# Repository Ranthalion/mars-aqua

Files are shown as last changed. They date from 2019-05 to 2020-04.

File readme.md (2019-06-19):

View this project on [CADLAB.io](https://cadlab.io/project/1833). 

# Mars Aqua Adapter
Adds support for pwm based dimming for Mars Aqua LED lights

Schematic

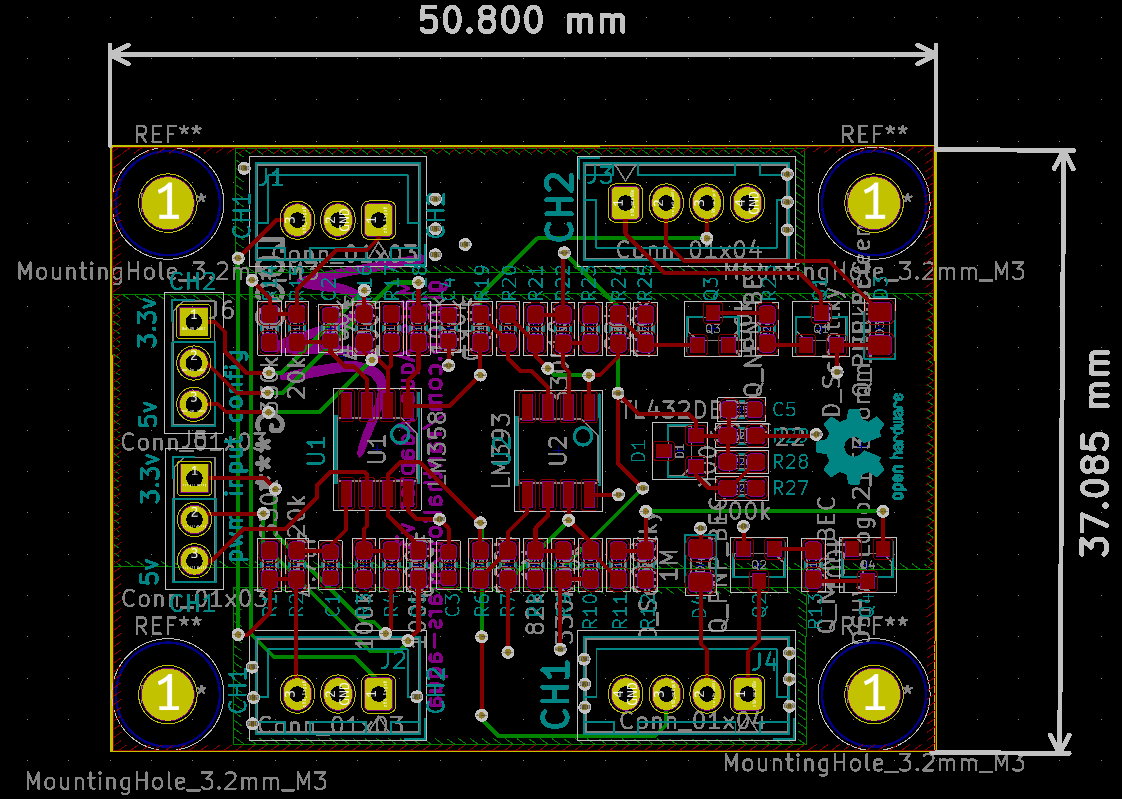
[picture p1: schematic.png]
Layout




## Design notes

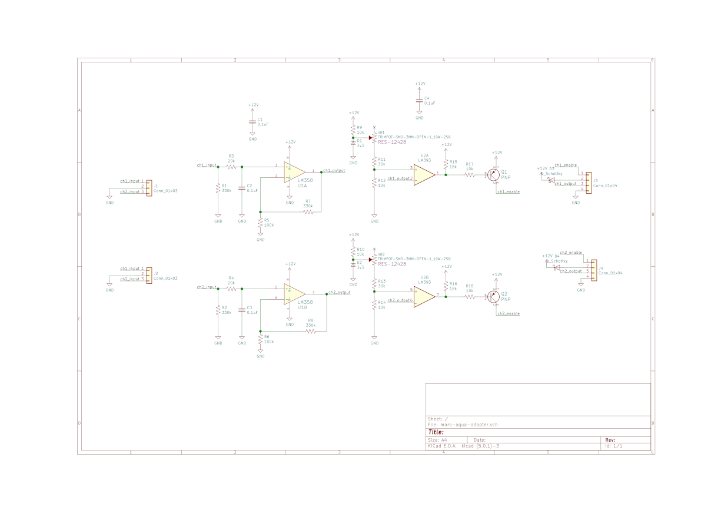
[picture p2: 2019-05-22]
mars-aqua-adapter-schematic.png

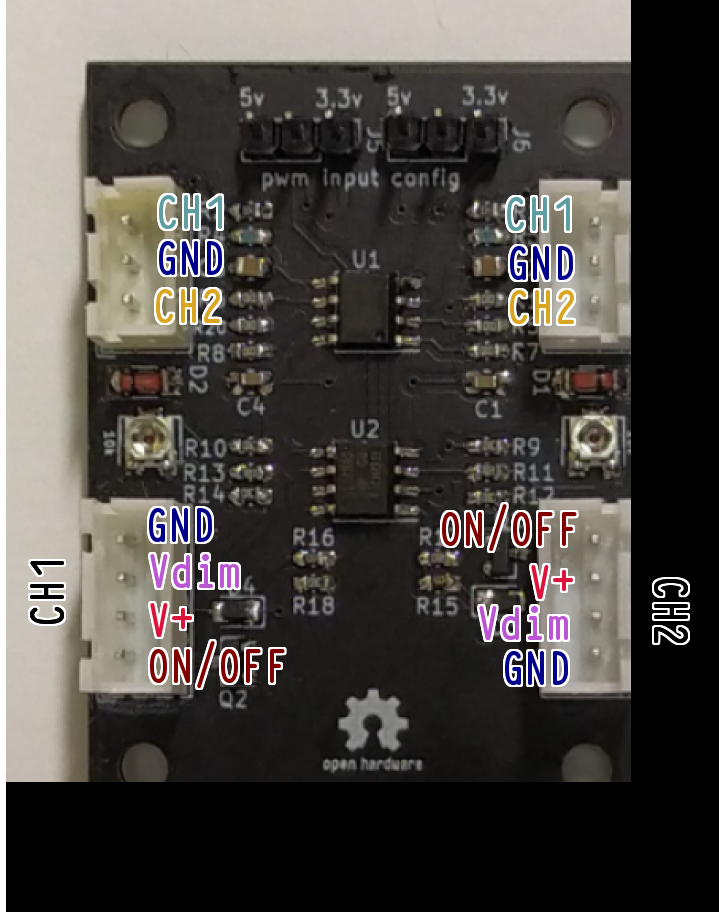
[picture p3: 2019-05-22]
annotated_pcb.png

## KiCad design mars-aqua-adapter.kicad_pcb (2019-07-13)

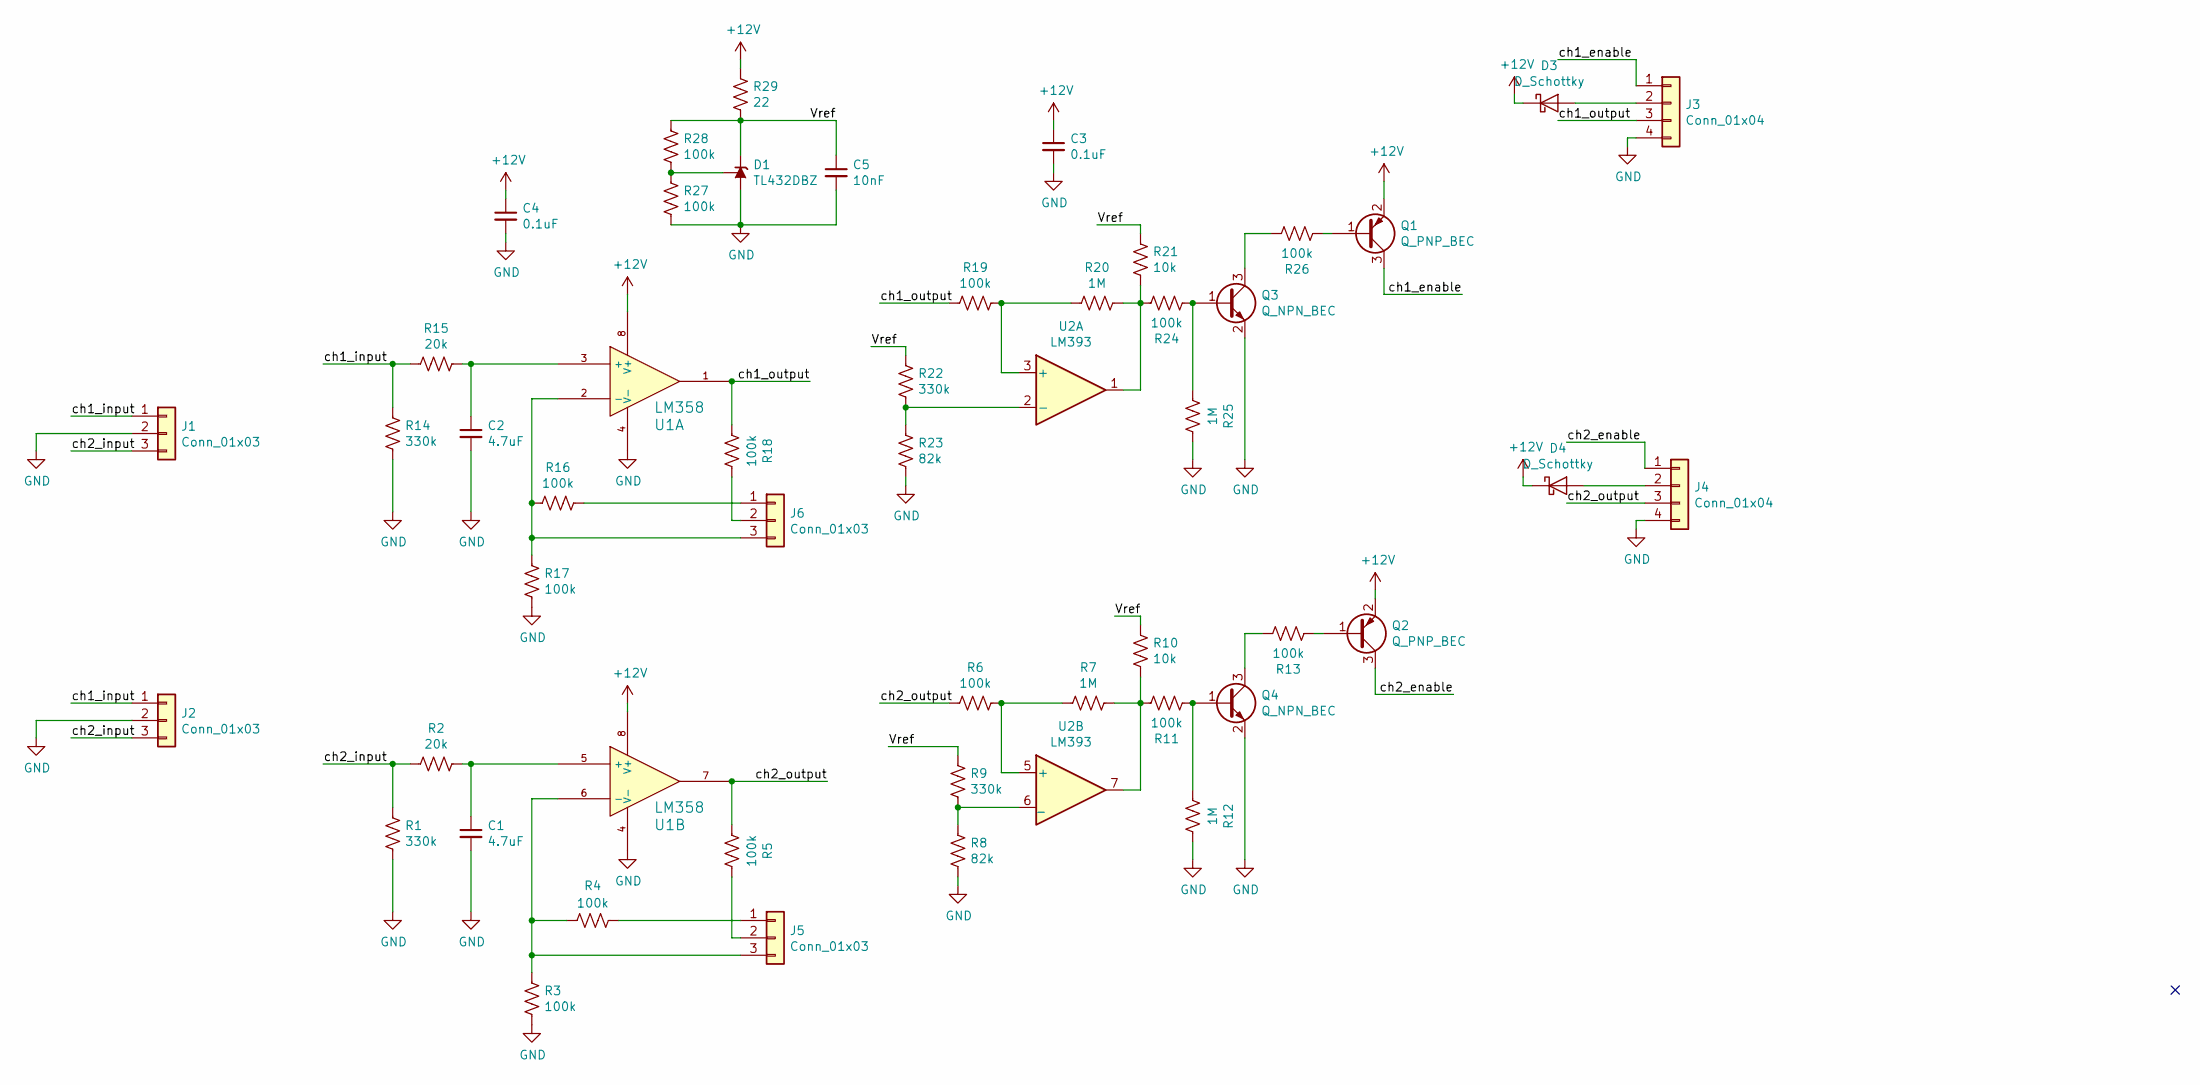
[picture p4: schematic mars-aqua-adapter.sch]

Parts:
C1, C2: 4.7uF; C_0603_1608Metric
C3, C4: 0.1uF; C_0603_1608Metric
C5: 10nF; C_0603_1608Metric
D1: TL432DBZ; SOT-23
D3, D4: D_Schottky; D_0805_2012Metric_Pad1.15x1.40mm_HandSolder
J1, J2: Conn_01x03; JST_XH_B03B-XH-A_1x03_P2.50mm_Vertical
J3, J4: Conn_01x04; JST_XH_B04B-XH-A_1x04_P2.50mm_Vertical
J5, J6: Conn_01x03; PinHeader_1x03_P2.54mm_Vertical
Q1, Q2: Q_PNP_BEC; SOT-23
Q3, Q4: Q_NPN_BEC; SOT-23
R1, R9, R14, R22: 330k; R_0603_1608Metric_Pad1.05x0.95mm_HandSolder
R2, R15: 20k; R_0603_1608Metric_Pad1.05x0.95mm_HandSolder
R3, R4, R5, R6, R11, R13, R16, R17, R18, R19, R24, R26, R27, R28: 100k; R_0603_1608Metric_Pad1.05x0.95mm_HandSolder
R7, R12, R20, R25: 1M; R_0603_1608Metric_Pad1.05x0.95mm_HandSolder
R8, R23: 82k; R_0603_1608Metric_Pad1.05x0.95mm_HandSolder
R10, R21: 10k; R_0603_1608Metric_Pad1.05x0.95mm_HandSolder
R29: 22; R_0603_1608Metric_Pad1.05x0.95mm_HandSolder
U1: LM358; SOIC-8_3.9x4.9mm_P1.27mm
U2: LM393; SOIC-8_3.9x4.9mm_P1.27mm

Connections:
+12V: C3.1, C4.1, D3.1 (K), D4.1 (K), Q1.2 (E), Q2.2 (E), R29.1, U1.8 (V+), U2.8 (V+)
/Vref: C5.1, D1.2 (K), R9.1, R10.1, R21.1, R22.1, R28.1, R29.2
/ch1_enable: J3.1, Q1.3 (C)
/ch1_input: J1.1, J2.1, R14.1, R15.2
/ch1_output: J3.3, R18.2, R19.2, U1.1
/ch2_enable: J4.1, Q2.3 (C)
/ch2_input: J1.3, J2.3, R1.1, R2.2
/ch2_output: J4.3, R5.2, R6.2, U1.7
GND: C1.2, C2.2, C3.2, C4.2, C5.2, D1.3 (A), J1.2, J2.2, J3.4, J4.4, Q3.2 (E), Q4.2 (E), R1.2, R3.2, R8.2, R12.1, R14.2, R17.2, R23.2, R25.1, R27.2, U1.4 (V-), U2.4 (V-)
unnamed: C1.1, R2.1, U1.5 (+)
unnamed: C2.1, R15.1, U1.3 (+)
unnamed: D1.1 (REF), R27.1, R28.2
unnamed: D3.2 (A), J3.2
unnamed: D4.2 (A), J4.2
unnamed: J5.1, R4.1
unnamed: J5.2, R5.1
unnamed: J5.3, R3.1, R4.2, U1.6 (-)
unnamed: J6.1, R16.1
unnamed: J6.2, R18.1
unnamed: J6.3, R16.2, R17.1, U1.2 (-)
unnamed: Q1.1 (B), R26.2
unnamed: Q2.1 (B), R13.2
unnamed: Q3.1 (B), R24.2, R25.2
unnamed: Q3.3 (C), R26.1
unnamed: Q4.1 (B), R11.2, R12.2
unnamed: Q4.3 (C), R13.1
unnamed: R6.1, R7.2, U2.5 (+)
unnamed: R8.1, R9.2, U2.6 (_)
unnamed: R7.1, R10.2, R11.1, U2.7
unnamed: R19.1, R20.2, U2.3 (+)
unnamed: R20.1, R21.2, R24.1, U2.1
unnamed: R22.2, R23.1, U2.2 (-)

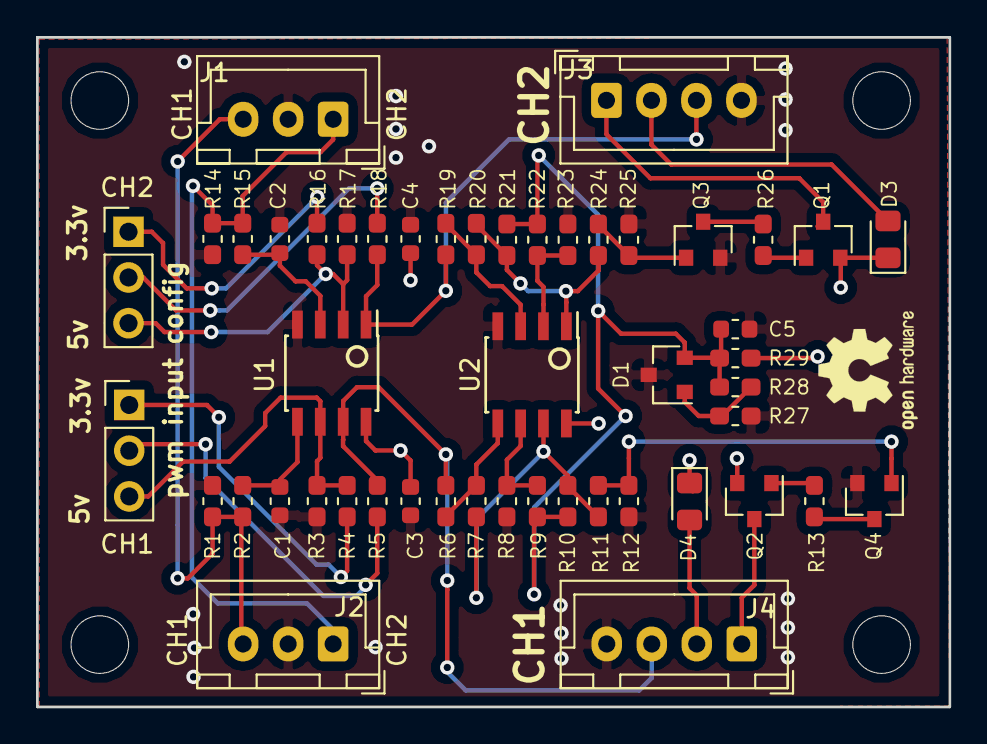
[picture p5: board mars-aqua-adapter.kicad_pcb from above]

Board: 2 copper layers, 50.7 x 37.2 mm, 49 parts (0 on the bottom side), 32 nets.

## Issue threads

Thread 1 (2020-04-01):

Updated Schematics?

spaelectronics, 2020-04-01:
Could you please update the schematics to your newest version?

I'm trying to trouble shoot some issues I'm having, but without the updated schematics, it makes it much harder.

Ranthalion, 2020-04-02:
The schematics haven't had any significant changes, but there were a couple of changes to resistor values.  Those changes are committed now.

Images have also been updated.

Closed 2020-04-02.

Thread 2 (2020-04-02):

Is the ON/OFF line current limited?

spaelectronics, 2020-04-02:
Is the ON/OFF line current limited, or are the transistors driven in saturation?

Ranthalion, 2020-04-02:
The on/off is designed to minimize current consumption since the board does not have a dedicated power source. Expected On/off current is only 1-2 mA. The transistors are not driven hard into saturation. R11, R13, R24, and R26 control this behavior (R13 and R26 most directly).

The On/Off line is floating when turned off. The original knob in the Mars Aqua lights uses a switch to close the connection when on, but open the connection when off.

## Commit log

2019-03-08 board layout
    [_saved_mars-aqua-adapter.sch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]
2019-03-09 Final Layout
    [_saved_mars-aqua-adapter.sch, mars-aqua-adapter.kicad_pcb, mars-aqua-adapter.sch]
2019-05-22 Fix traces on comparator
    [mars-aqua-adapter-B.Cu.gbr, mars-aqua-adapter-B.Mask.gbr, mars-aqua-adapter-B.Paste.gbr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]
2019-05-22 Updated schematic image and add annotated pcb
2019-05-27 Add hysteresis
    [mars-aqua-adapter-B.Cu.gbr, mars-aqua-adapter-B.Mask.gbr, mars-aqua-adapter-B.SilkS.gbr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]
2019-06-19 Add voltage reference
    [_saved_mars-aqua-adapter.sch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]
2019-07-13 gerber updates
    [_saved_mars-aqua-adapter.sch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]
2019-07-15 update feedback and regulator values
    [mars-aqua-adapter.sch]
2020-04-02 Update values
    [mars-aqua-adapter.sch]
